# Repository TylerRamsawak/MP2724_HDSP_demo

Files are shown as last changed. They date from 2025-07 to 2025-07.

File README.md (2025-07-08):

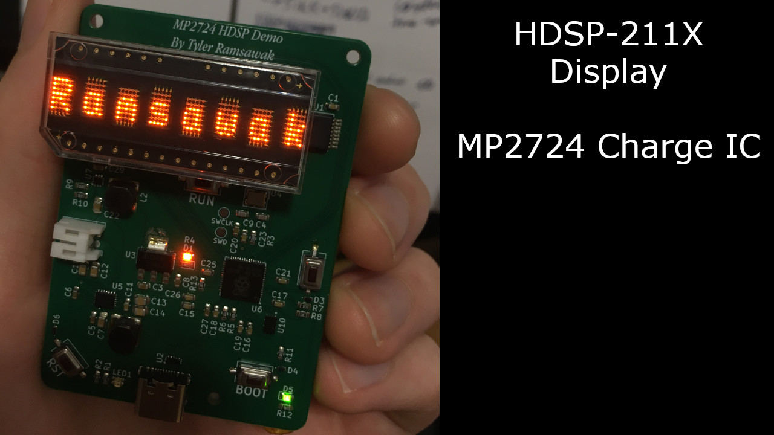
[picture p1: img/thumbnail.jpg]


A board I made to play with an old HDSP-211X display commonly found in Motorola MicroTAC series of phones. The charger IC is an MP2724, featuring I2C, USB-C cc protocol, legacy DPDM port detection, OVP, timers, watchdogs, you name it. And its capable of charging at 2A with 3A FETs! I can't begin to describe how long I've looked for a charger just like this.<br>

The board consists of an RP2040 that controls the MP2724 via I2C, and controls the HDSP via a serial->parallel 74HC595.<br>

This is in the series towards rebuilding my Motorola MicroTAC phones.<br>

Check out the video! <a href="https://www.youtube.com/watch?v=8jdg8jAGuHc"> How I Make Circuit Boards at Home | MP2724 HDSP Demo</a><br>
(https://www.youtube.com/watch?v=8jdg8jAGuHc)

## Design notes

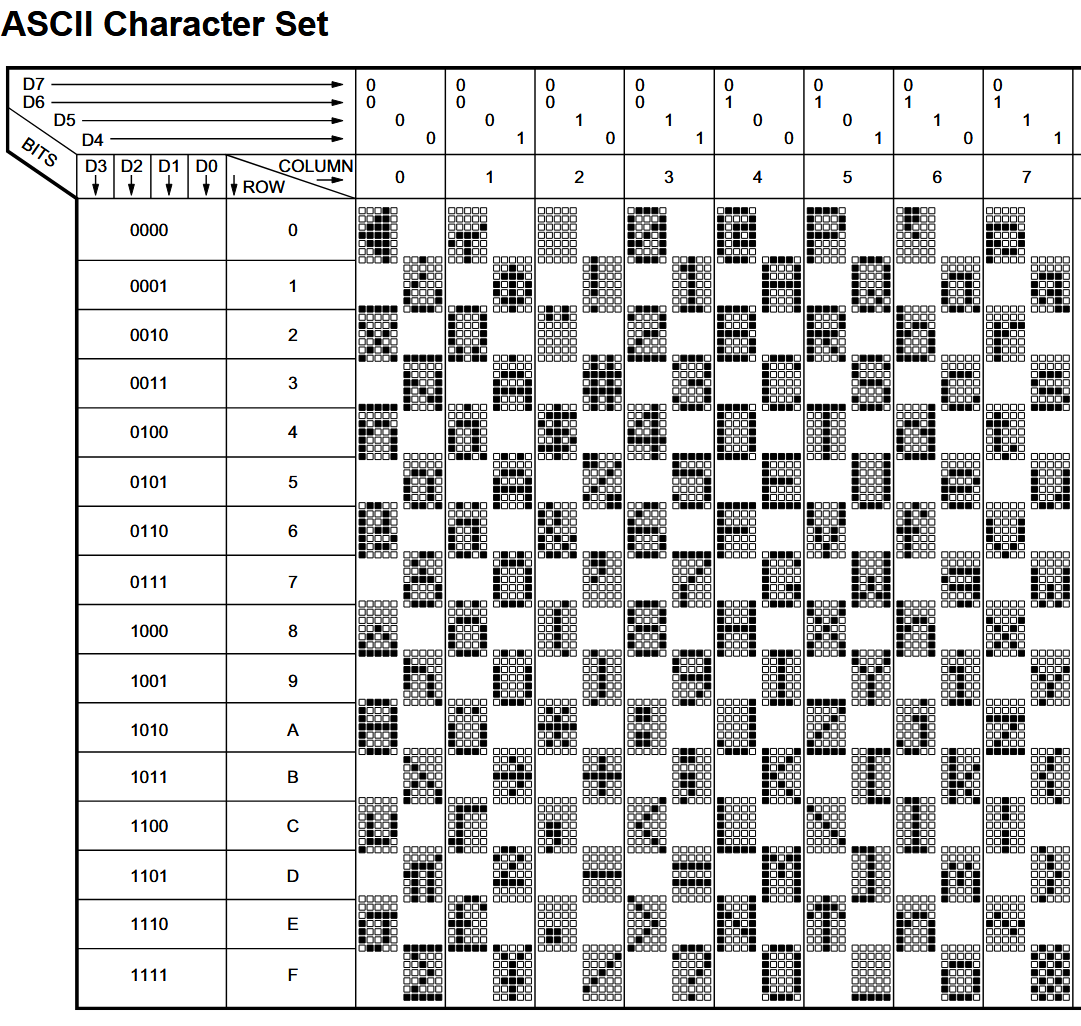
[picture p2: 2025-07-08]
img/char_set.PNG

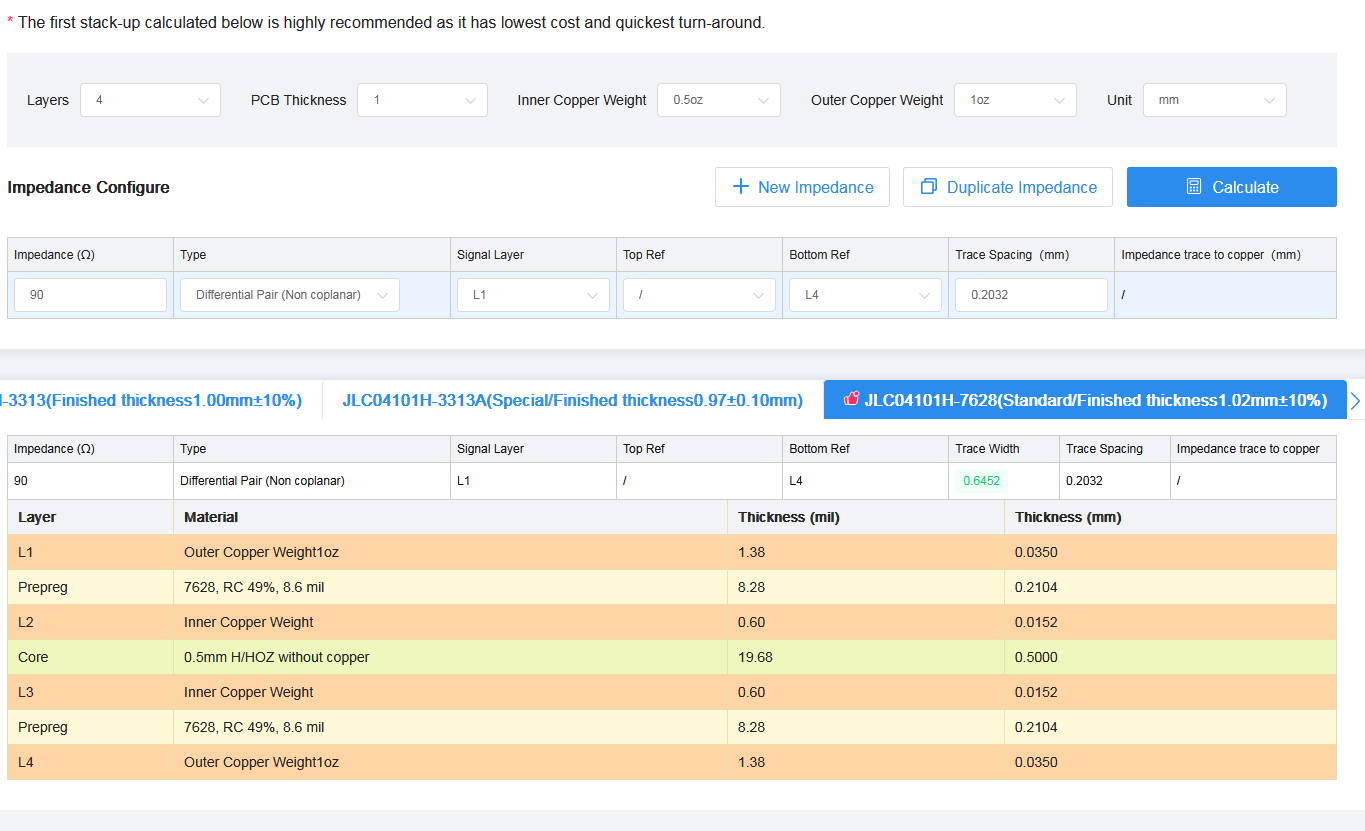
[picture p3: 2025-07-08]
img/stackup.PNG

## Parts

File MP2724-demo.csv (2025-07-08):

Reference | Value | Datasheet | Footprint | Qty | DNP
BT1 | Battery | ~ | Connector_JST:JST_PH_S2B-PH-K_1x02_P2.00mm_Horizontal | 1
C1,C2,C15,C16,C17,C18,C19,C21,C23,C25,C26 | 100nF | ~ | Capacitor_SMD:C_0603_1608Metric | 11
C3,C6,C8 | 4.7uF | ~ | Capacitor_SMD:C_0603_1608Metric | 3
C4,C9 | 15pF | ~ | Capacitor_SMD:C_0603_1608Metric | 2
C5,C20,C27 | 1uF | ~ | Capacitor_SMD:C_0603_1608Metric | 3
C7,C10,C12,C13,C14,C22 | 10uF | ~ | Capacitor_SMD:C_0805_2012Metric | 6
C11 | 22nF | ~ | Capacitor_SMD:C_0603_1608Metric | 1
C28,C29 | 22uF | ~ | Capacitor_SMD:C_0603_1608Metric | 2
D1,D5 | LED | ~ | LED_SMD:LED_0603_1608Metric | 2
D2,D3,D4,D6 | ESD351 | ~ | Diode_SMD:D_0402_1005Metric | 4
J1 | USB_C_Receptacle_USB2.0_16P | https://www.usb.org/sites/default/files/documents/usb_type-c.zip | UJ20:UJ20-C-H-G-SMT-1-P16-TR | 1
J2 | Conn_02x14_Counter_Clockwise | ~ | Package_DIP:DIP-28_W15.24mm | 1
L1,L2 | 1uH | ~ | HPC5040NV:HPC 5040NV-1R0M | 2
LED1 | LTST-C195KGJRKT | https://lcsc.com/product-detail/Light-Emitting-Diodes-LED_SMD-green-red_C125104.html | easyeda2kicad:LED-ARRAY-SMD_0603-4P-L1.6-W1.5-BR-RD | 1
R1,R2,R3,R4,R11,R12 | 1k | ~ | Resistor_SMD:R_0603_1608Metric | 6
R5,R6 | 27.4 | ~ | Resistor_SMD:R_0603_1608Metric | 2
R7,R8,R13 | 10k | ~ | Resistor_SMD:R_0603_1608Metric | 3
R9 | 732k | ~ | Resistor_SMD:R_0603_1608Metric | 1
R10 | 100k | ~ | Resistor_SMD:R_0603_1608Metric | 1
SW1,SW2,SW3,SW4 | SW_Push | https://www.ckswitches.com/media/2779/pts636.pdf | Button_Switch_SMD:SW_Tactile_SPST_NO_Straight_CK_PTS636Sx25SMTRLFS | 4
TP1,TP2,TP3,TP4 | TestPoint_Small | ~ | TestPoint:TestPoint_Pad_D1.5mm | 4
U1 | 74HC595 | http://www.ti.com/lit/ds/symlink/sn74hc595.pdf | Package_SO:SSOP-16_5.3x6.2mm_P0.65mm | 1
U2 | TPD4E05U06DQAR |  | Package_SON:USON-10_2.5x1.0mm_P0.5mm | 1
U3 | AP2114HA-3.3TRG1 | https://lcsc.com/product-detail/Low-Dropout-Regulators-LDO_Diodes-Incorporated-AP2114HA-3-3TRG1_C460314.html | easyeda2kicad:SOT-223-3_L6.5-W3.4-P2.30-LS7.0-BR | 1
U4 | ABM8-272-T3_C20625731 |  | easyeda2kicad:CRYSTAL-SMD_4P-L3.2-W2.5-BL | 1
U5 | MP2724GRH |  | MP2724:MP2724GRH | 1
U6 | RP2040 | https://datasheets.raspberrypi.com/rp2040/rp2040-datasheet.pdf | Package_DFN_QFN:QFN-56-1EP_7x7mm_P0.4mm_EP3.2x3.2mm | 1
U7 | TPS61023DRLR |  | Package_TO_SOT_SMD:SOT-563 | 1
U10 | W25Q16JVUXIO | http://www.winbond.com/resource-files/w25q32jv%20revg%2003272018%20plus.pdf | IC_W25Q16JVUXIQ_TR:IC_W25Q16JVUXIQ_TR | 1

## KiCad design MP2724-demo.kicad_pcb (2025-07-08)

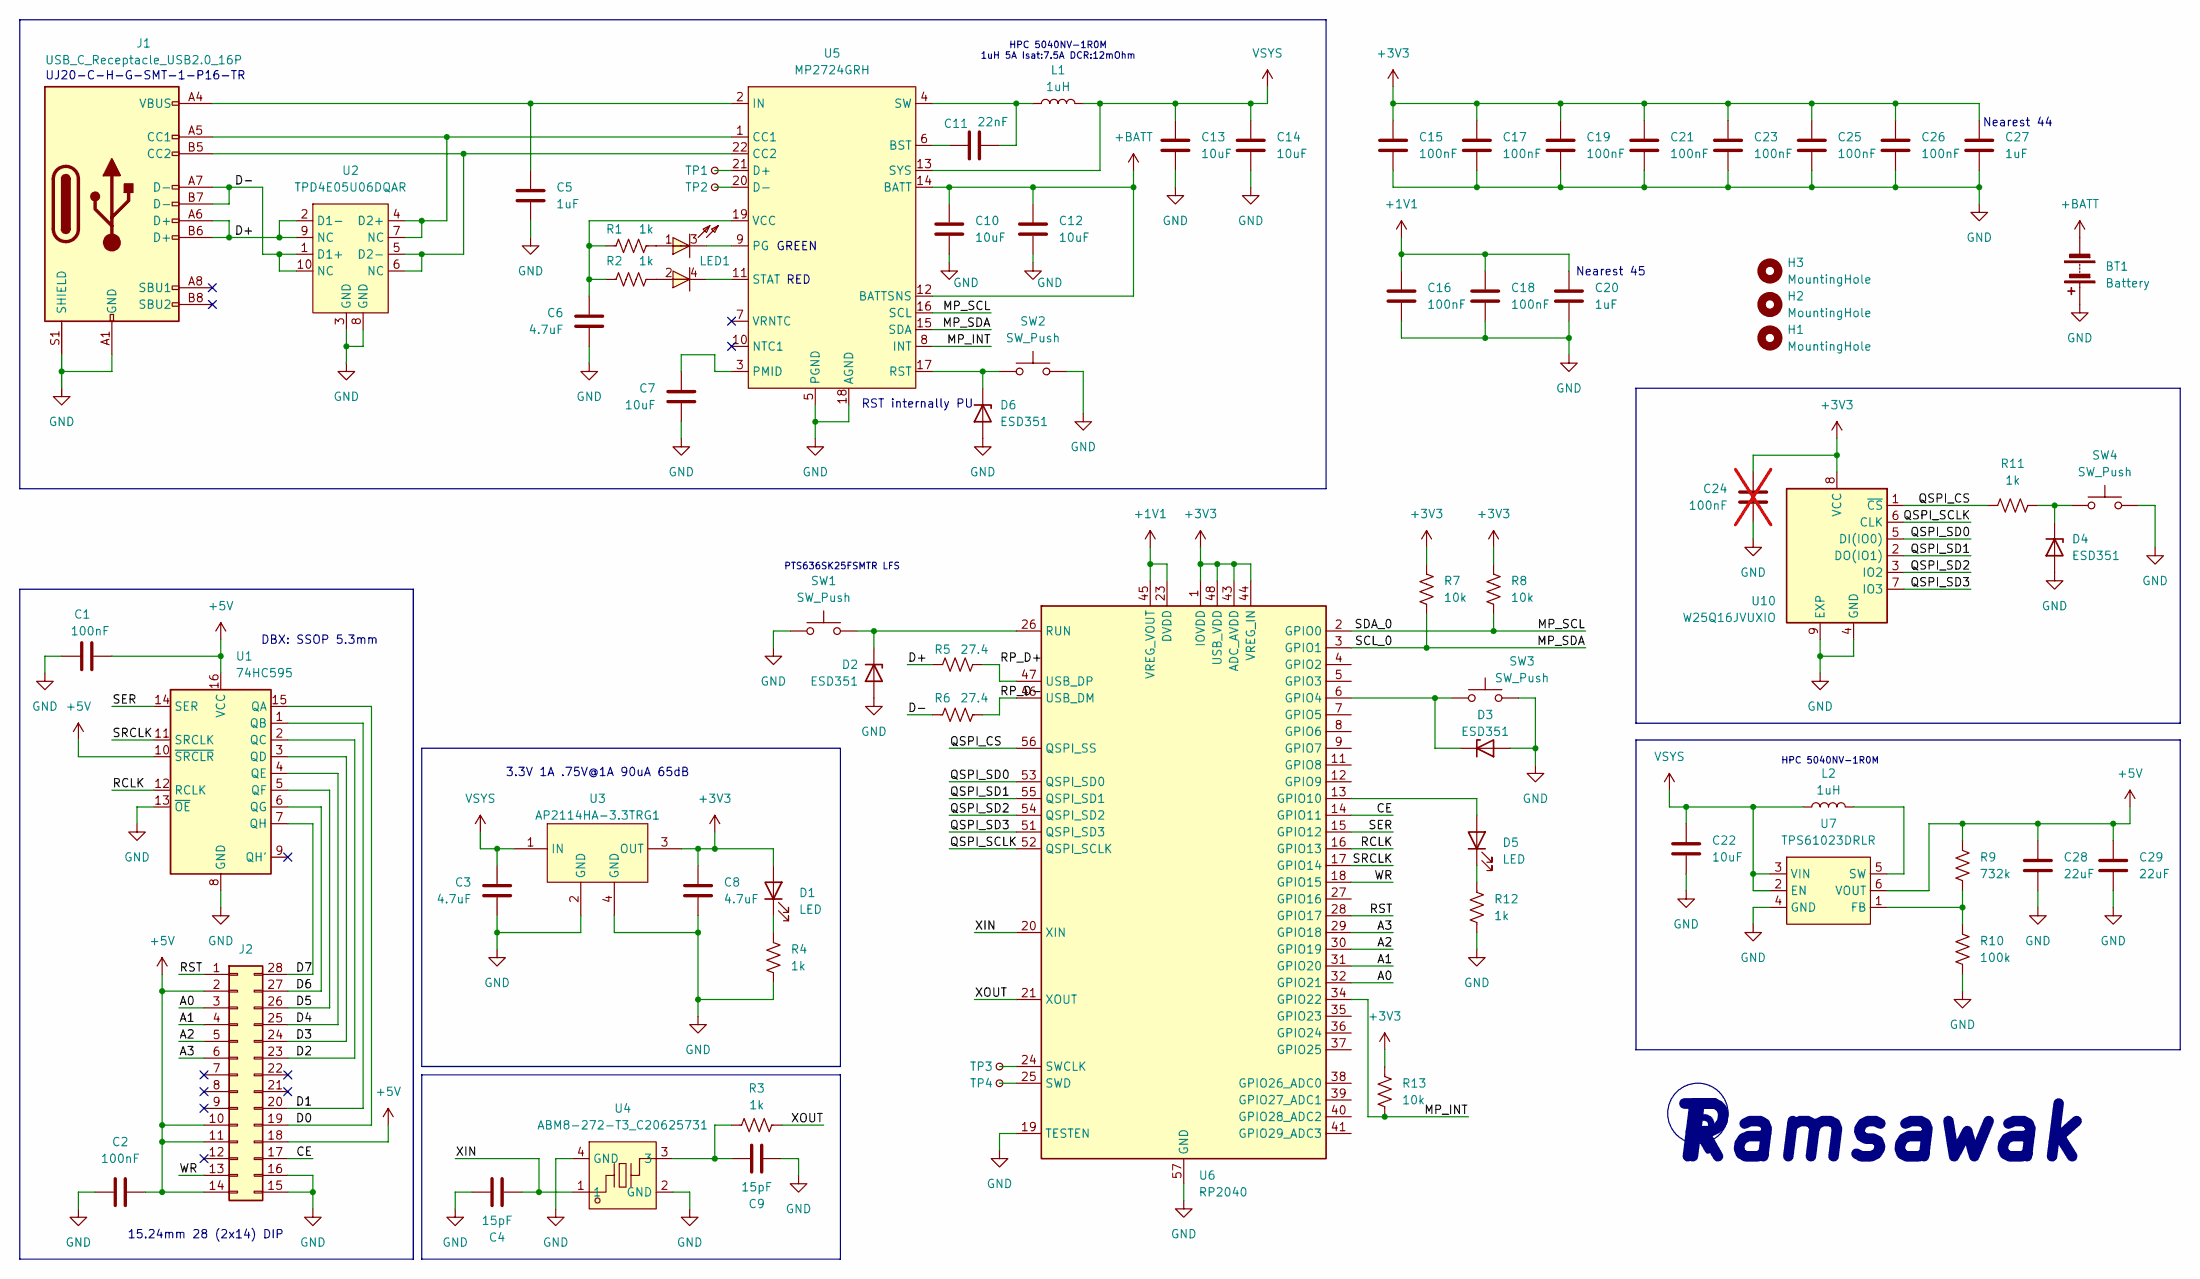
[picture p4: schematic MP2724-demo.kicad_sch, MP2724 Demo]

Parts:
BT1: Battery; JST_PH_S2B-PH-K_1x02_P2.00mm_Horizontal
C1, C2, C15, C16, C17, C18, C19, C21, C23, C25, C26: 100nF; C_0603_1608Metric
C3, C6, C8: 4.7uF; C_0603_1608Metric
C4, C9: 15pF; C_0603_1608Metric
C5, C20, C27: 1uF; C_0603_1608Metric
C7, C10, C12, C13, C14, C22: 10uF; C_0805_2012Metric
C11: 22nF; C_0603_1608Metric
C24: 100nF; C_0603_1608Metric; not fitted
C28, C29: 22uF; C_0603_1608Metric
D1, D5: LED; LED_0603_1608Metric
D2, D3, D4, D6: ESD351; D_0402_1005Metric
H1, H2, H3: MountingHole; MountingHole_2.2mm_M2
J1: USB_C_Receptacle_USB2.0_16P; UJ20-C-H-G-SMT-1-P16-TR
J2: Conn_02x14_Counter_Clockwise; DIP-28_W15.24mm
L1, L2: 1uH; HPC 5040NV-1R0M
LED1: LTST-C195KGJRKT; LED-ARRAY-SMD_0603-4P-L1.6-W1.5-BR-RD; LCSC Part C125104
R1, R2, R3, R4, R11, R12: 1k; R_0603_1608Metric
R5, R6: 27.4; R_0603_1608Metric
R7, R8, R13: 10k; R_0603_1608Metric
R9: 732k; R_0603_1608Metric
R10: 100k; R_0603_1608Metric
SW1, SW2, SW3, SW4: SW_Push; SW_Tactile_SPST_NO_Straight_CK_PTS636Sx25SMTRLFS
TP1, TP2, TP3, TP4: TestPoint_Small; TestPoint_Pad_D1.5mm
U1: 74HC595; SSOP-16_5.3x6.2mm_P0.65mm
U2: TPD4E05U06DQAR; USON-10_2.5x1.0mm_P0.5mm
U3: AP2114HA-3.3TRG1; SOT-223-3_L6.5-W3.4-P2.30-LS7.0-BR; LCSC Part C460314
U4: ABM8-272-T3_C20625731; CRYSTAL-SMD_4P-L3.2-W2.5-BL; LCSC Part C20625731
U5: MP2724GRH
U6: RP2040; QFN-56-1EP_7x7mm_P0.4mm_EP3.2x3.2mm
U7: TPS61023DRLR; SOT-563
U10: W25Q16JVUXIO; IC_W25Q16JVUXIQ_TR

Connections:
+1V1: C16.1, C18.1, C20.1, U6.23 (DVDD), U6.45 (VREG_VOUT), U6.50 (DVDD)
+3V3: C8.1, C15.1, C17.1, C19.1, C21.1, C23.1, C24.1, C25.1, C26.1, C27.1, D1.2 (A), R7.1, R8.1, R13.1, U3.3 (OUT), U6.1 (IOVDD), U6.10 (IOVDD), U6.22 (IOVDD), U6.33 (IOVDD), U6.42 (IOVDD), U6.43 (ADC_AVDD), U6.44 (VREG_IN), U6.48 (USB_VDD), U6.49 (IOVDD), U10.8 (VCC)
+5V: C1.1, C2.1, C28.1, C29.1, J2.2, J2.10, J2.11, J2.14, J2.18, R9.1, U1.10 (~SRCLR), U1.16 (VCC), U7.6 (VOUT)
+BATT: BT1.2 (-), C10.1, C12.1, U5.12 (BATTSNS), U5.14 (BATT)
/A0: J2.3, U6.32 (GPIO21)
/A1: J2.4, U6.31 (GPIO20)
/A2: J2.5, U6.30 (GPIO19)
/A3: J2.6, U6.29 (GPIO18)
/CE: J2.17, U6.14 (GPIO11)
/D0: J2.19, U1.15 (QA)
/D1: J2.20, U1.1 (QB)
/D2: J2.23, U1.2 (QC)
/D3: J2.24, U1.3 (QD)
/D4: J2.25, U1.4 (QE)
/D5: J2.26, U1.5 (QF)
/D6: J2.27, U1.6 (QG)
/D7: J2.28, U1.7 (QH)
/D+: J1.A6 (D+), J1.B6 (D+), R5.1, U2.2 (D1-), U2.9 (NC)
/D-: J1.A7 (D-), J1.B7 (D-), R6.1, U2.1 (D1+), U2.10 (NC)
/MP_INT: R13.2, U5.8 (INT), U6.34 (GPIO22)
/MP_SCL: R8.2, U5.16 (SCL), U6.2 (GPIO0)
/MP_SDA: R7.2, U5.15 (SDA), U6.3 (GPIO1)
/QSPI_CS: R11.1, U6.56 (QSPI_SS), U10.1 (~CS)
/QSPI_SCLK: U6.52 (QSPI_SCLK), U10.6 (CLK)
/QSPI_SD0: U6.53 (QSPI_SD0), U10.5 (DI(IO0))
/QSPI_SD1: U6.55 (QSPI_SD1), U10.2 (DO(IO1))
/QSPI_SD2: U6.54 (QSPI_SD2), U10.3 (IO2)
/QSPI_SD3: U6.51 (QSPI_SD3), U10.7 (IO3)
/RCLK: U1.12 (RCLK), U6.16 (GPIO13)
/RP_D+: R5.2, U6.47 (USB_DP)
/RP_D-: R6.2, U6.46 (USB_DM)
/RST: J2.1, U6.28 (GPIO17)
/SER: U1.14 (SER), U6.15 (GPIO12)
/SRCLK: U1.11 (SRCLK), U6.17 (GPIO14)
/WR: J2.13, U6.18 (GPIO15)
/XIN: C4.2, U4.1, U6.20 (XIN)
/XOUT: R3.2, U6.21 (XOUT)
GND: BT1.1 (+), C1.2, C2.2, C3.2, C4.1, C5.2, C6.2, C7.2, C8.2, C9.2, C10.2, C12.2, C13.2, C14.2, C15.2, C16.2, C17.2, C18.2, C19.2, C20.2, C21.2, C22.2, C23.2, C24.2, C25.2, C26.2, C27.2, C28.2, C29.2, D2.2 (A), D3.2 (A), D4.2 (A), D6.2 (A), J1.A1 (GND), J1.A12 (GND), J1.B1 (GND), J1.B12 (GND), J1.S1 (SHIELD), J2.15, J2.16, R4.2, R10.2, R12.2, SW1.2, SW2.2, SW3.2, SW4.2, U1.8 (GND), U1.13 (~OE), U2.3 (GND), U2.8 (GND), U3.2 (GND), U3.4 (GND), U4.2 (GND), U4.4 (GND), U5.5 (PGND), U5.18 (AGND), U6.19 (TESTEN), U6.57 (GND), U7.4 (GND), U10.4 (GND), U10.9 (EXP)
unnamed: C9.1, R3.1, U4.3
unnamed: D1.1 (K), R4.1
unnamed: D2.1 (K), SW1.1, U6.26 (RUN)
unnamed: D3.1 (K), SW3.1, U6.6 (GPIO4)
unnamed: D4.1 (K), R11.2, SW4.1
unnamed: D5.2 (A), U6.13 (GPIO10)
unnamed: D5.1 (K), R12.1
unnamed: D6.1 (K), SW2.1, U5.17 (RST)
unnamed: J1.A5 (CC1), U2.4 (D2+), U2.7 (NC), U5.1 (CC1)
unnamed: J1.B5 (CC2), U2.5 (D2-), U2.6 (NC), U5.22 (CC2)
unnamed: LED1.1, R1.2
unnamed: LED1.2, R2.2
unnamed: C11.1, U5.6 (BST)
unnamed: TP1.1, U5.21 (D+)
unnamed: TP2.1, U5.20 (D-)
unnamed: C5.1, J1.A4 (VBUS), J1.A9 (VBUS), J1.B4 (VBUS), J1.B9 (VBUS), U5.2 (IN)
unnamed: LED1.3, U5.9 (PG)
unnamed: C7.1, U5.3 (PMID)
unnamed: LED1.4, U5.11 (STAT)
unnamed: C11.2, L1.1, U5.4 (SW)
unnamed: C6.1, R1.1, R2.1, U5.19 (VCC)
unnamed: TP3.1, U6.24 (SWCLK)
unnamed: TP4.1, U6.25 (SWD)
unnamed: R9.2, R10.1, U7.1 (FB)
unnamed: L2.2, U7.5 (SW)
VSYS: C3.1, C13.1, C14.1, C22.1, L1.2, L2.1, U3.1 (IN), U5.13 (SYS), U7.2 (EN), U7.3 (VIN)

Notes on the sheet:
Nearest 45
HPC 5040NV-1R0M
GREEN
Ramsawak
PTS636SK25FSMTR LFS
3.3V 1A .75V@1A 90uA 65dB
UJ20-C-H-G-SMT-1-P16-TR
15.24mm 28 (2x14) DIP
Nearest 44
RED
RST internally PU
HPC 5040NV-1R0M 1uH 5A Isat:7.5A DCR:12mOhm
DBX: SSOP 5.3mm

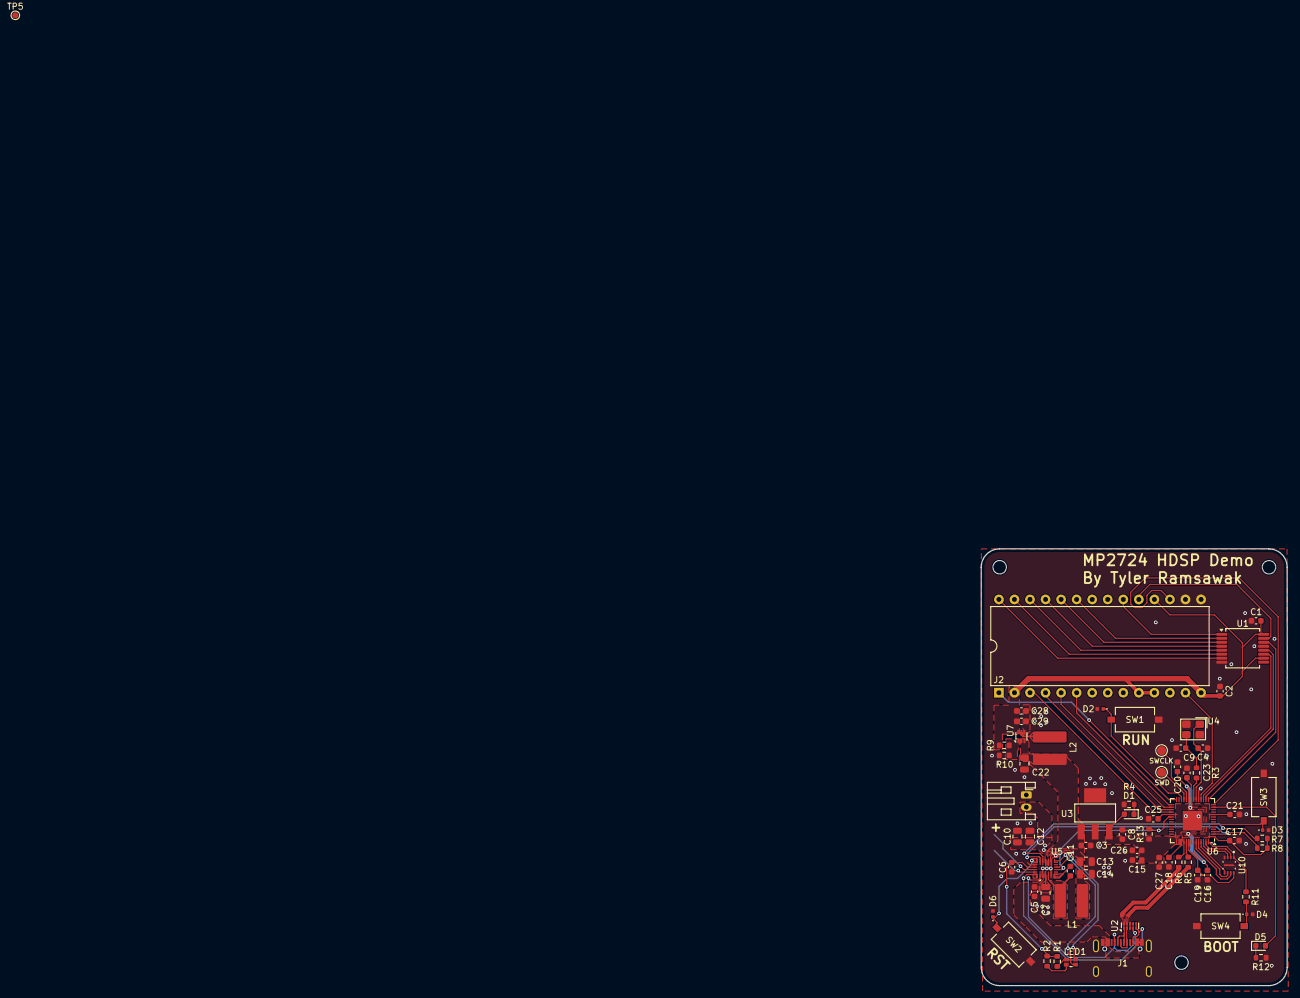
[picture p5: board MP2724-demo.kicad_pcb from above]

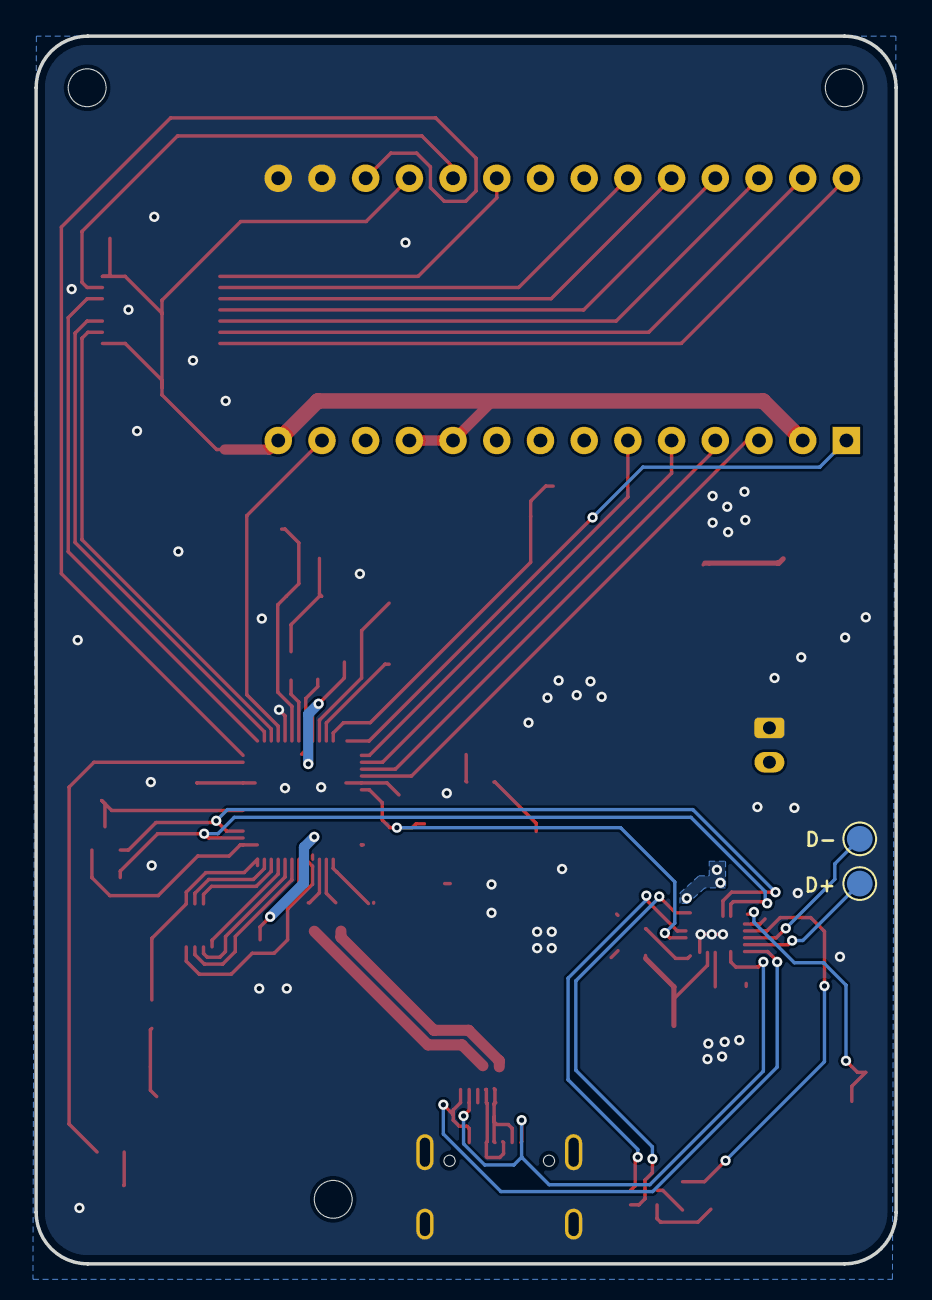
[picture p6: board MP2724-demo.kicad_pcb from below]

Board: 4 copper layers, 50.0 x 71.4 mm, 73 parts (2 on the bottom side), 64 nets.

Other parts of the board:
TP5: TestPoint_Small; TestPoint_Pad_D1.0mm

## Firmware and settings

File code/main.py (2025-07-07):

from machine import Pin
from sr74hc595 import SR74HC595_BITBANG
from hdsp import HDSP_controller
import time
import utime

led = Pin(10, Pin.OUT)


#74HC595
ser = Pin(12, Pin.OUT)
rclk = Pin(13, Pin.OUT)
srclk = Pin(14, Pin.OUT)

sr = SR74HC595_BITBANG(ser, srclk, rclk)


#HDSP-2113
A0 = Pin(21, Pin.OUT)
A1 = Pin(20, Pin.OUT)
A2 = Pin(19, Pin.OUT)
A3 = Pin(18, Pin.OUT)
rst = Pin(17, Pin.OUT)
wr = Pin(15, Pin.OUT)
ce = Pin(11, Pin.OUT)

display = HDSP_controller(A0, A1, A2, A3, rst, wr, ce)

display.reset()

def update_display(time):
    char_codes = []
    for i, char in enumerate(time):
        char_code = display.get_char_code(char) #returns 18 since char='H'
        sr.bits(char_code, 8)
        sr.latch()
        position = 8-len(time)+i
        display.char_position(position)
        display.write_cycle()


hour = 14
minute = 16
second = 00

last_update = utime.time()

while True:
    current_time = utime.time()
    
    if current_time - last_update >= 1:
        elapsed = current_time - last_update
        last_update = current_time

        # Update seconds, minutes, and hours
        second += elapsed
        if second >= 60:
            minute += second // 60
            second = second % 60
        if minute >= 60:
            hour += minute // 60
            minute = minute % 60
        if hour >= 24:
            hour = hour % 24
            
        update_display(f'{hour}:{minute}:{second}')
    utime.sleep(0.1)

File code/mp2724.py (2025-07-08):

#MP2724 by Tyler Ramsawak


class MP2724_i2c:
    def __init__(self, i2c, addr=0x3F):
        self.i2c = i2c
        self.addr = addr
    
    #read register
    def peek(self, reg):
        return self.i2c.readfrom_mem(self.addr, reg, 1)[0]
    
    #write to register
    def poke(self, reg):
        return None
    
    #extract bits from register
    def bf(self, reg, msb, lsb=None):
        data = self.peek(reg) & 0xFF
                
        if lsb is None:
            width = 1
            extracted_value = (data >> msb) & 0b1
        else:
            width = msb - lsb + 1
            mask = (1 << width) - 1
            extracted_value = (data >> lsb) & mask
        
        return f'{extracted_value:0{width}b}'
    
    
    #CHG_CTRL0
    def reg_rst(self):
        return self.bf(0x00, 7)
    
    def en_stat_ib(self):
        return self.bf(0x00, 6)
    
    def en_pg_ntc2(self):
        return self.bf(0x00, 5)
    
    def lock_chg(self):
        return self.bf(0x00, 4)
    
    def holdoff_tmr(self):
        return self.bf(0x00, 3)
    
    def sw_freq(self):
        return self.bf(0x00, 2, 1)
    
    def en_vin_trk(self):
        return self.bf(0x00, 0)
    
    #IIN
    def iin_mode(self):
        return self.bf(0x01, 7, 5)
    
    def iin_lim(self):
        return self.bf(0x01, 4, 0)
    
    #CHG_PARAMETER0
    def vpre(self):
        return self.bf(0x02, 7, 6)
    def icc(self):
        return self.bf(0x02, 5, 0)
    
    #CHG_PARAMETER1
    def ipre(self):
        return self.bf(0x03, 7, 4)
    
    def iterm(self):
        return self.bf(0x03, 3, 0)
    
    #CHG_PARAMETER2
    def vrechg(self):
        return self.bf(0x04, 7)
    
    def itrickle(self):
        return self.bf(0x04, 6, 4)
    
    def vin_lim(self):
        return self.bf(0x04, 3, 0)
    
    #CHG_PARAMETER3
    def topoff_tmr(self):
        return self.bf(0x05, 7, 6)
    
    def vbatt(self):
        return self.bf(0x05, 5, 0)
    
    #CHG_CTRL1
    def sys_min(self):
        return self.bf(0x06, 5, 3)
    
    def treg(self):
        return self.bf(0x06, 2, 0)
    
    #CHG_CTRL2
    def ib_en(self):
        return self.bf(0x07, 7)
    
    def watchdog_rst(self):
        return self.bf(0x07, 6)
    
    def watchdog(self):
        return self.bf(0x07, 5, 4)
    
    def en_term(self):
        return self.bf(0x07, 3)
    
    def en_tmr2x(self):
        return self.bf(0x07, 2)
    
    def chg_timer(self):
        return self.bf(0x07, 1, 0)
    
    #CHG_CTRL3
    def battfet_dis(self):
        return self.bf(0x08, 7)
    
    def battfet_dly(self):
        return self.bf(0x08, 6)
    
    def battfet_rst_en(self):
        return self.bf(0x08, 5)
    
    def olim(self):
        return self.bf(0x08, 4, 3)
    
    def vboost(self):
        return self.bf(0x08, 2, 0)
    
    #CHG_CTRL4
    def cc_cfg(self):
        return self.bf(0x09, 6, 4)
    
    def en_boost(self):
        return self.bf(0x09, 2)
    
    def en_buck(self):
        return self.bf(0x09, 1)
    
    def en_cng(self):
        return self.bf(0x09, 0)
    
    #VIN_DET
    def autodpm(self):
        return self.bf(0x0A, 5)
    
    def forcedpdm(self):
        return self.bf(0x0A, 4)
    
    def force_cc(self):
        return self.bf(0x0A, 1, 0)
    
    #CHG_CTRL5
    def ntc1_action(self):
        return self.bf(0x0C, 6)
    
    def ntc2_action(self):
        return self.bf(0x0C, 5)
    
    def batt_ovp_en(self):
        return self.bf(0x0C, 4)
    
    def batt_low(self):
        return self.bf(0x0C, 3, 2)
    
    def boost_stp_en(self):
        return self.bf(0x0C, 1)
    
    def boost_otp_en(self):
        return self.bf(0x0C, 0)
    
    #NTC_ACTION
    def warm_act(self):
        return self.bf(0x0D, 7, 6)
    
    def cool_act(self):
        return self.bf(0x0D, 5, 4)
    
    def jeita_vset(self):
        return self.bf(0x0D, 3, 2)
    
    def jeita_iset(self):
        return self.bf(0x0D, 1, 0)
    
    #NTC_TH
    def vhot(self):
        return self.bf(0x0E, 7, 6)
    
    def vwarm(self):
        return self.bf(0x0E, 5, 4)
    
    def vcool(self):
        return self.bf(0x0E, 3, 2)
    
    def vcold(self):
        return self.bf(0x0E, 1, 0)
    
    #VIN_IMPD
    def vin_src_en(self):
        return self.bf(0x0F, 6)
    
    def ivin_src(self):
        return self.bf(0x0F, 5, 2)
    
    def vin_test(self):
        return self.bf(0x0F, 1, 0)
    
    #INT_MASK
    def mask_therm(self):
        return self.bf(0x10, 6)
    
    def mask_dpm(self):
        return self.bf(0x10, 4)
    
    def mask_topoff(self):
        return self.bf(0x10, 3)
    
    def mask_cc_int(self):
        return self.bf(0x10, 2)
    
    def mask_batt_low(self):
        return self.bf(0x10, 1)
    
    def mask_debug(self):
        return self.bf(0x10, 0)
    
    #STATUS0
    def dpdm_stat(self):
        return self.bf(0x11, 7, 4)
    
    def vindpm_stat(self):
        return self.bf(0x11, 1)
    
    def iindpm_stat(self):
        return self.bf(0x11, 0)
    
    #STATUS1
    def vin_gd(self):
        return self.bf(0x12, 6)
    
    def vin_rdy(self):
        return self.bf(0x12, 5)
    
    def legacycable(self):
        return self.bf(0x12, 4)
    
    def therm_stat(self):
        return self.bf(0x12, 3)
    
    def vsys_stat(self):
        return self.bf(0x12, 2)
    
    def watchdog_dault(self):
        return self.bf(0x12, 1)
    
    def watchdog_bark(self):
        return self.bf(0x12, 0)
    
    #STATUS2
    def chg_stat(self):
        return self.bf(0x13, 7, 5)
    
    def boost_dault(self):
        return self.bf(0x13, 4, 2)
    
    def chg_fault(self):
        return self.bf(0x13, 1, 0)
    
    #STATUS3
    def ntc_missing(self):
        return self.bf(0x14, 7)
    
    def batt_missing(self):
        return self.bf(0x14, 6)
    
    def ntc1_fault(self):
        return self.bf(0x14, 5, 3)
    
    def ntc2_fault(self):
        return self.bf(0x14, 2, 0)
    
    #STATUS4
    def cc1_sink_stat(self):
        return self.bf(0x15, 7, 6)
    
    def cc2_sink_stat(self):
        return self.bf(0x15, 5, 4)
    
    #STATUS5
    def topoff_active(self):
        return self.bf(0x16, 6)
    
    def bfet_stat(self):
        return self.bf(0x16, 5)
    
    def batt_low_stat(self):
        return self.bf(0x16, 4)
    
    def vin_test_high(self):
        return self.bf(0x16, 2)
    
    def debugacc(self):
        return self.bf(0x16, 1)
